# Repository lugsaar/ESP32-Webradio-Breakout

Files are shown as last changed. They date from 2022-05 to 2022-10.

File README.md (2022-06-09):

# ESP32-Webradio-Breakout

This project is a basic board to build an ESP32 webradio. All components like the microcontroller, 
display and the power supply should be compactly placed on a kind of breakout board. As an idea we used a
[blog article](https://www.az-delivery.de/blogs/azdelivery-blog-fur-arduino-und-raspberry-pi/internet-radio-mit-dem-esp32) 
of the company AZ-Delivery in March 2022. You only need a small handful of electronic components execpt 
an ESP32 development board and a I2C display.

By choosing a switching regulator for the power supply, leftover power supplies e.g. of an old scanner, 
PC speakers or similar can be used to run the board. From defective devices one has these power supplies
often lie around and can recycle them so here.

## technical details

coming later

## current state

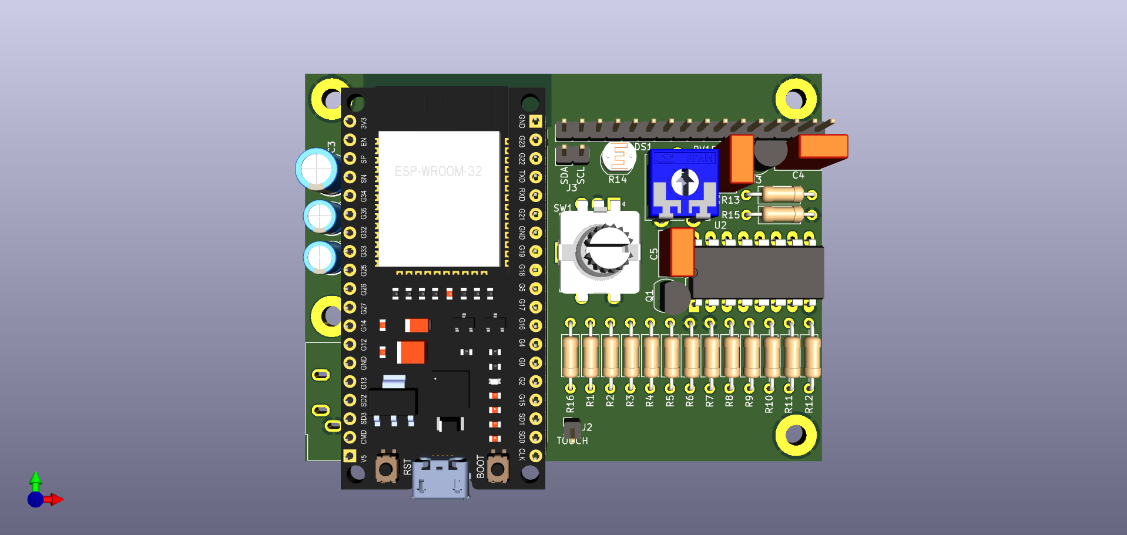
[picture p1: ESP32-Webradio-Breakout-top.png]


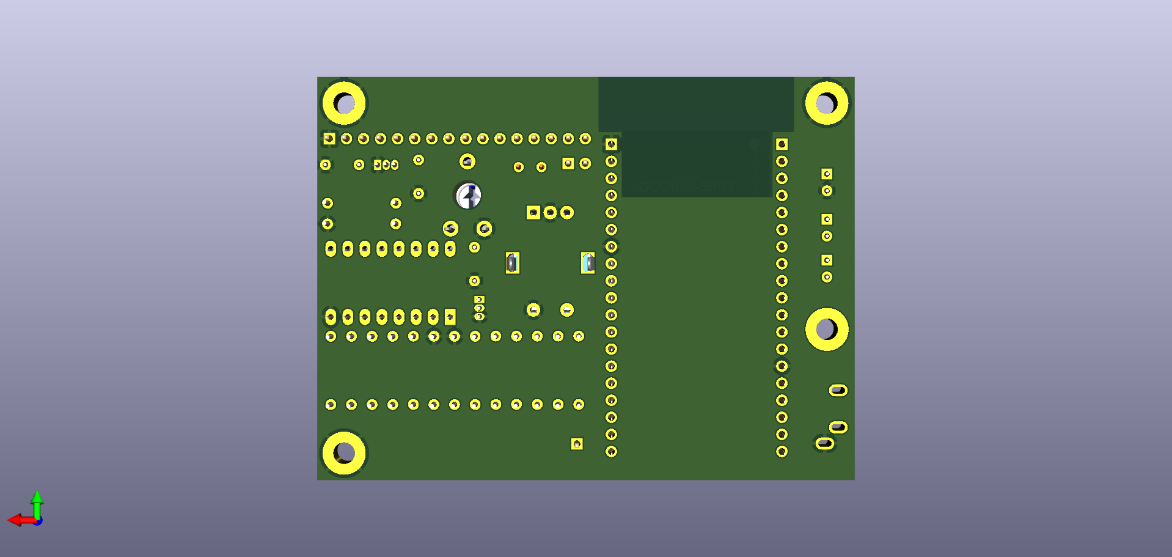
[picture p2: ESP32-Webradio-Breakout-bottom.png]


## maintained

- [Dominik](mailto:dominik@lug-saar.de) (LUG-Saar)
- [Manfred](mailto:mancas@lug-saar.de) (LUG-Saar)
- [Thomas](mailto:mase@setho.org) (TKS)

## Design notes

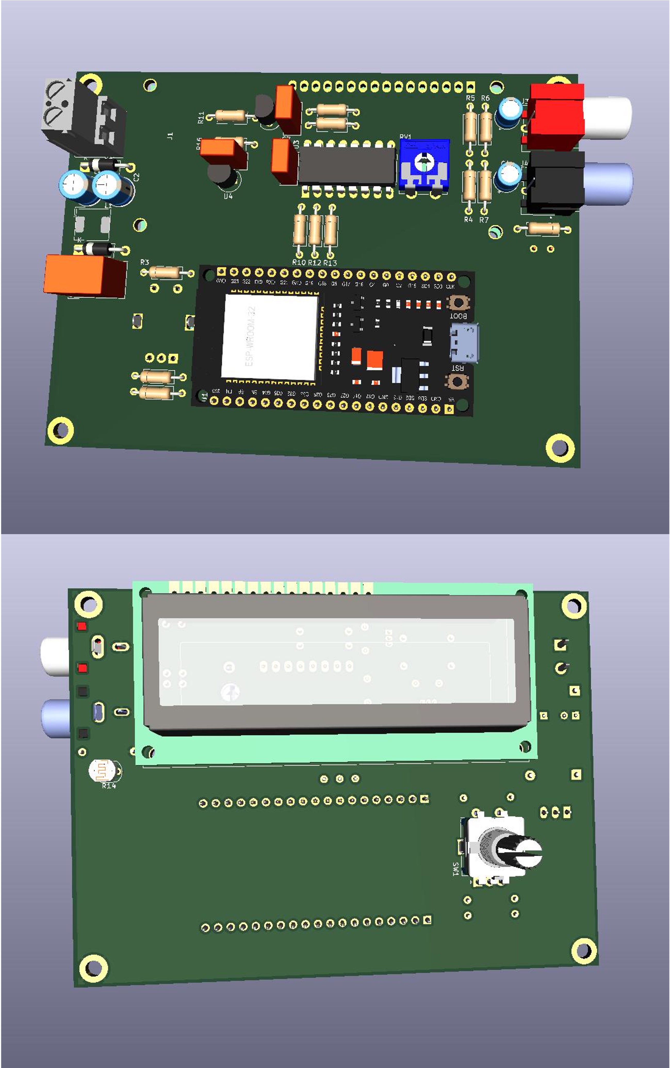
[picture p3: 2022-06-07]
ESP32-Webradio-Breakout.jpg

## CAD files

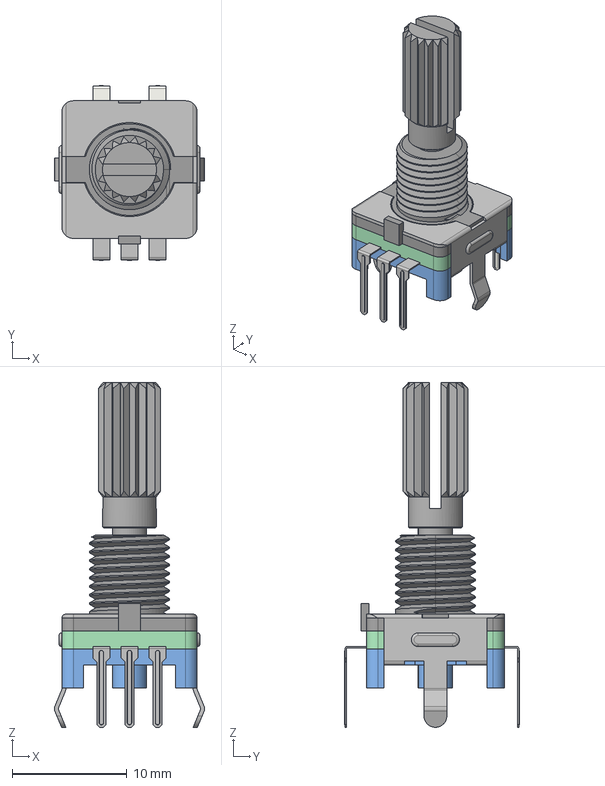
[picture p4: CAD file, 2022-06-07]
3D Models/EC11_Rotary_Encoder_Switched.step
13.1 x 15.3 x 30.1 mm

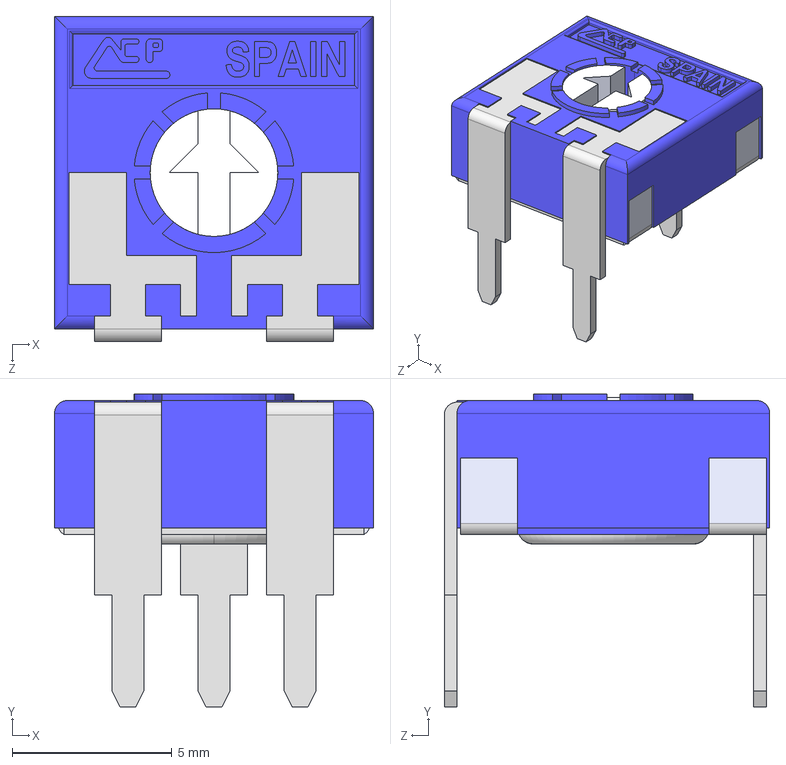
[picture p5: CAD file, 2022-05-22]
3D Models/Potentiometer_ACP_CA9-V10_Vertical_Hole.step
10.0 x 9.80 x 10.2 mm

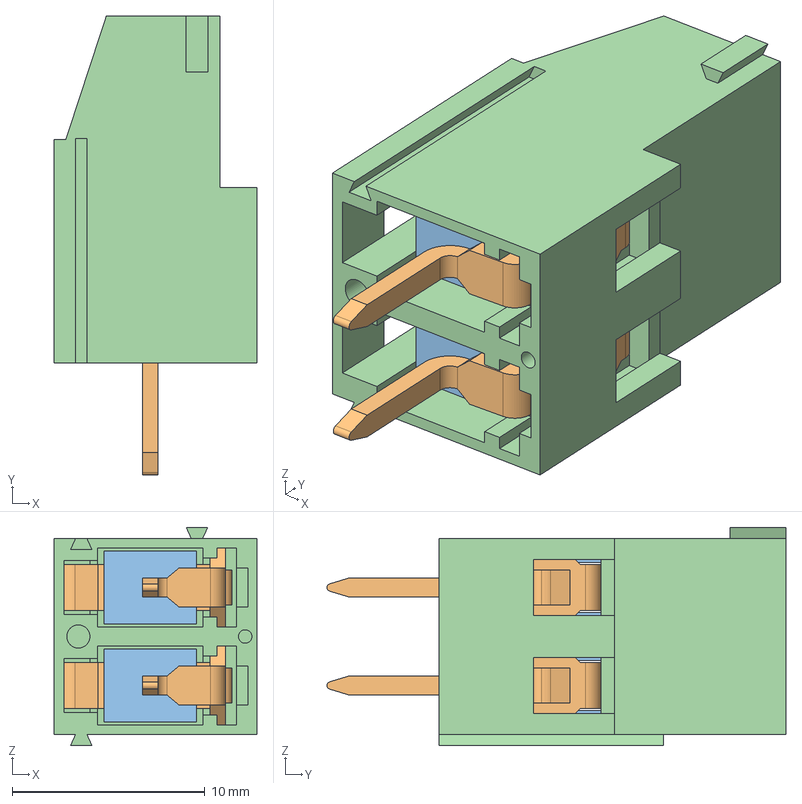
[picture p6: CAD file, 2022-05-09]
3D Models/TerminalBlock_RND_205-00287_1x02_P5.08mm_Horizontal.stp
10.5 x 23.8 x 11.3 mm

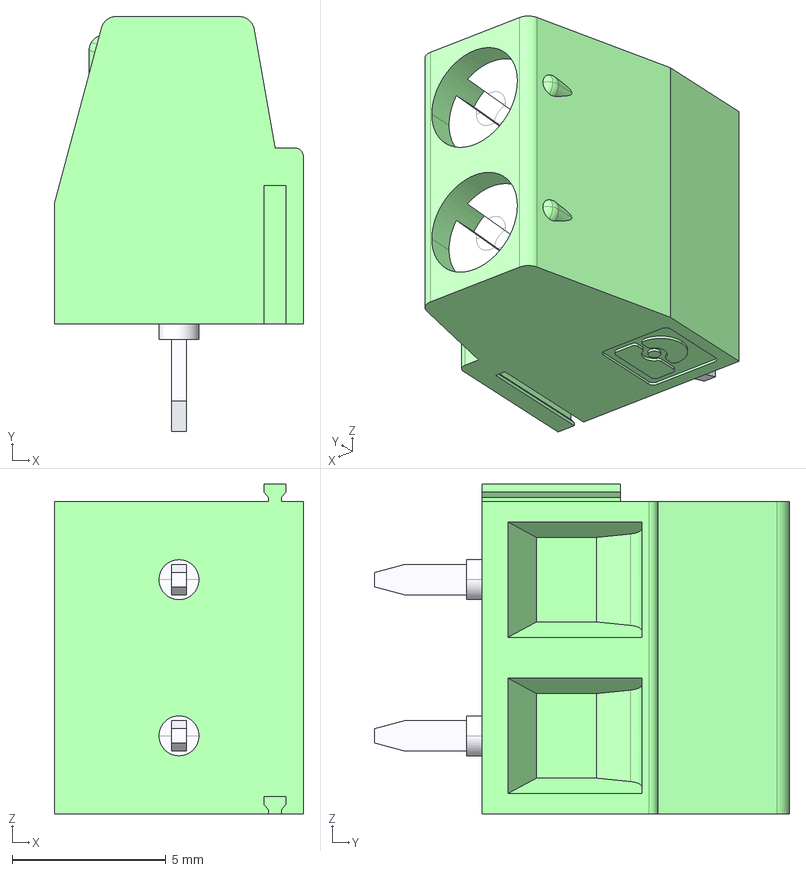
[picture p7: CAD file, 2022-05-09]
3D Models/TerminalBlock_Phoenix_MKDSN-1,5-2-5.08_1x02_P5.08mm_Horizontal.stp
8.10 x 13.5 x 10.7 mm

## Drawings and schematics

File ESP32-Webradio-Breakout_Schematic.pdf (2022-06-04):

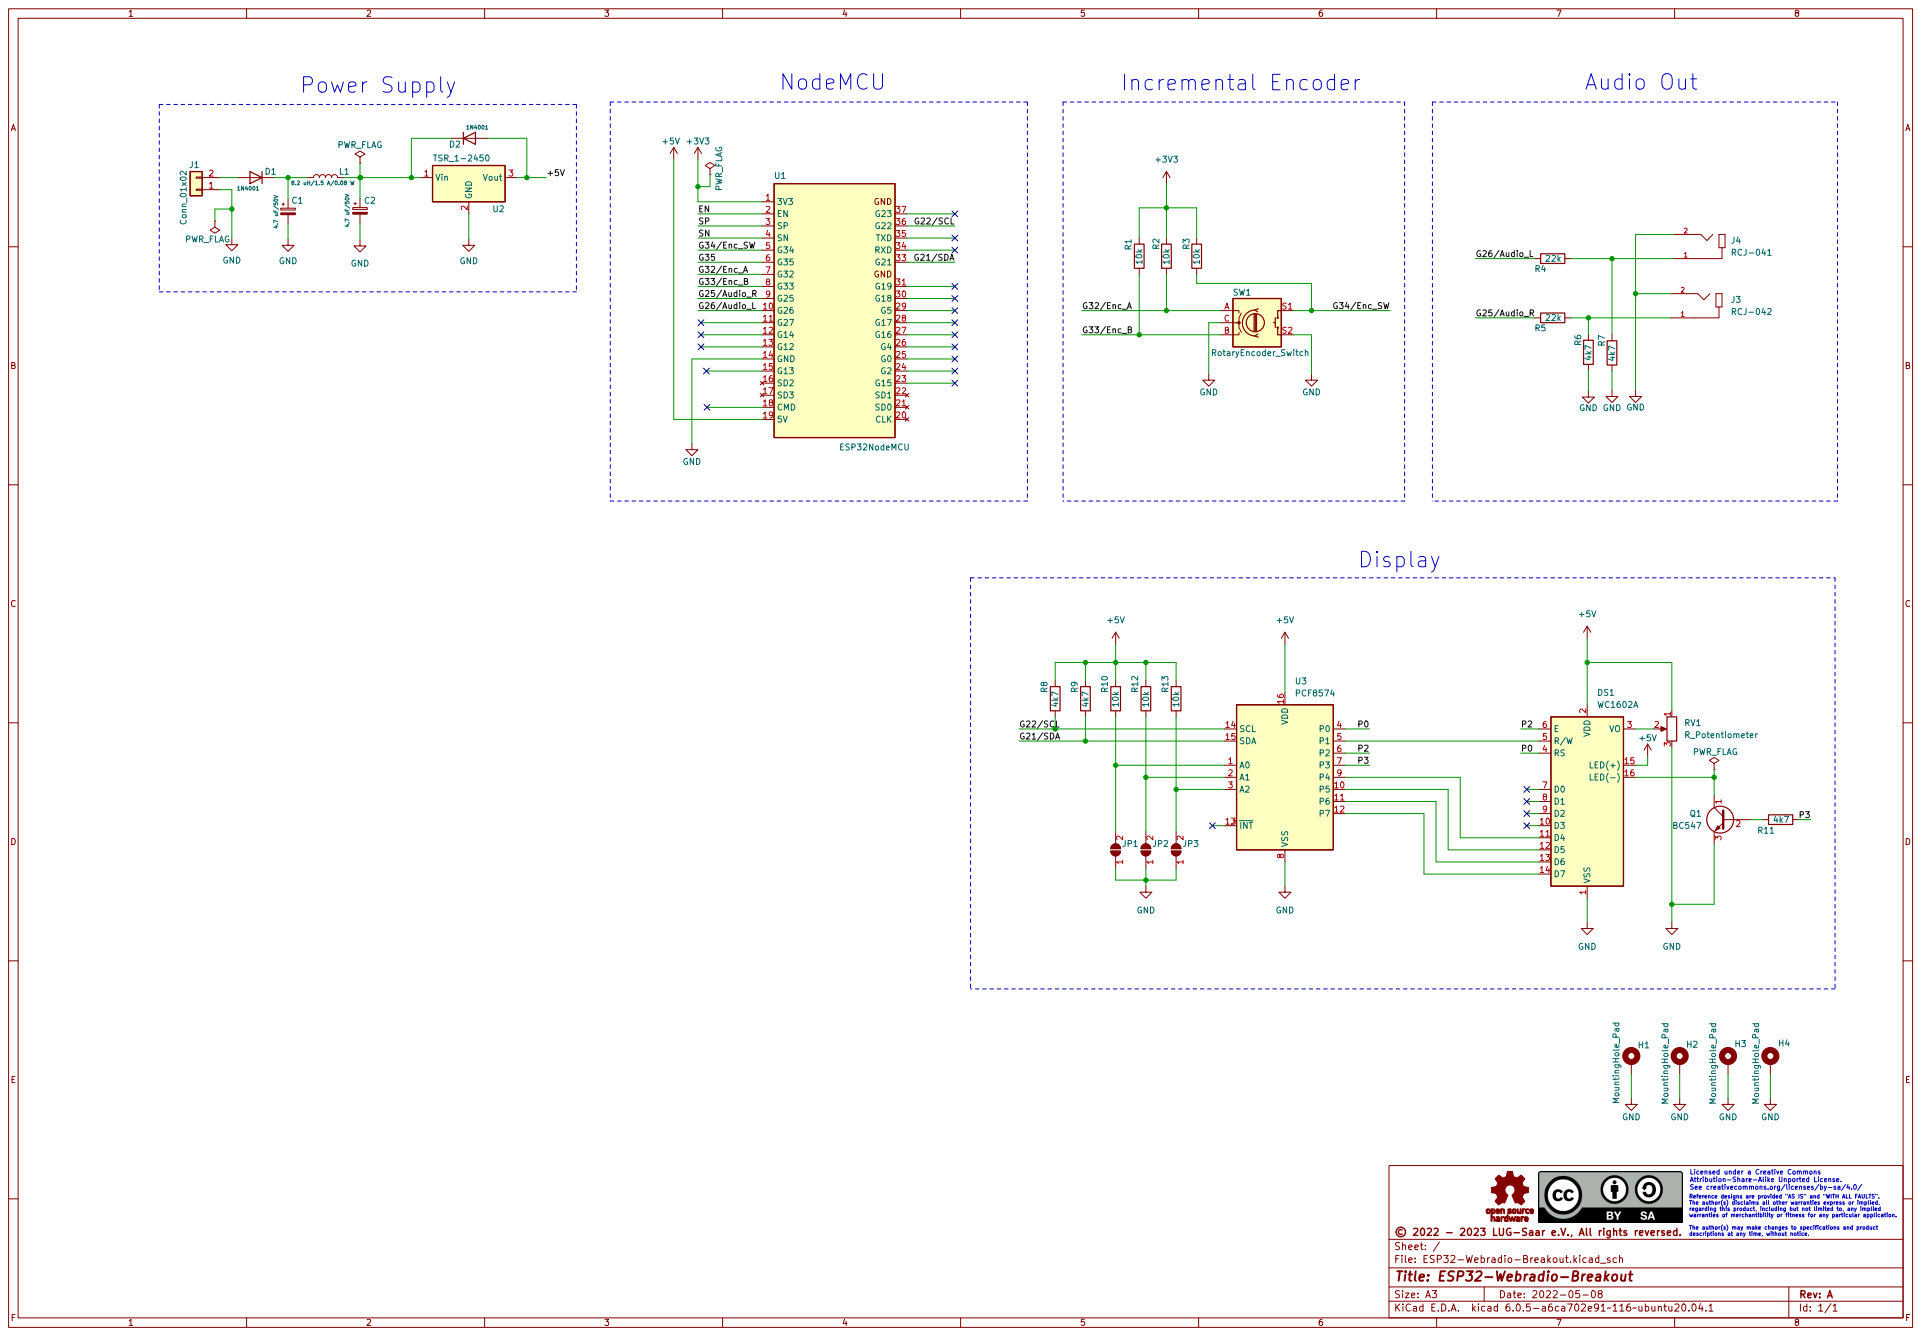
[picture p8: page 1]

Reference designs are provided "AS IS" and "WITH ALL FAULTS". The author(s) disclaims all other warranties express or implied, regarding this product, including but not limited to, any implied warranties of merchantibility or fitness for any particular application. The author(s) may make changes to specifications and product descriptions at any time, without notice. Licensed under a Creative Commons Attribution-Share-Alike Unported License. See creativecommons.org/licenses/by-sa/4.0/

File: ESP32-Webradio-Breakout.kicad_sch Sheet: / þÿ© 2022 - 2023 LUG-Saar e.V., All rights reversed.

Id: 1/1 Title: ESP32-Webradio-Breakout

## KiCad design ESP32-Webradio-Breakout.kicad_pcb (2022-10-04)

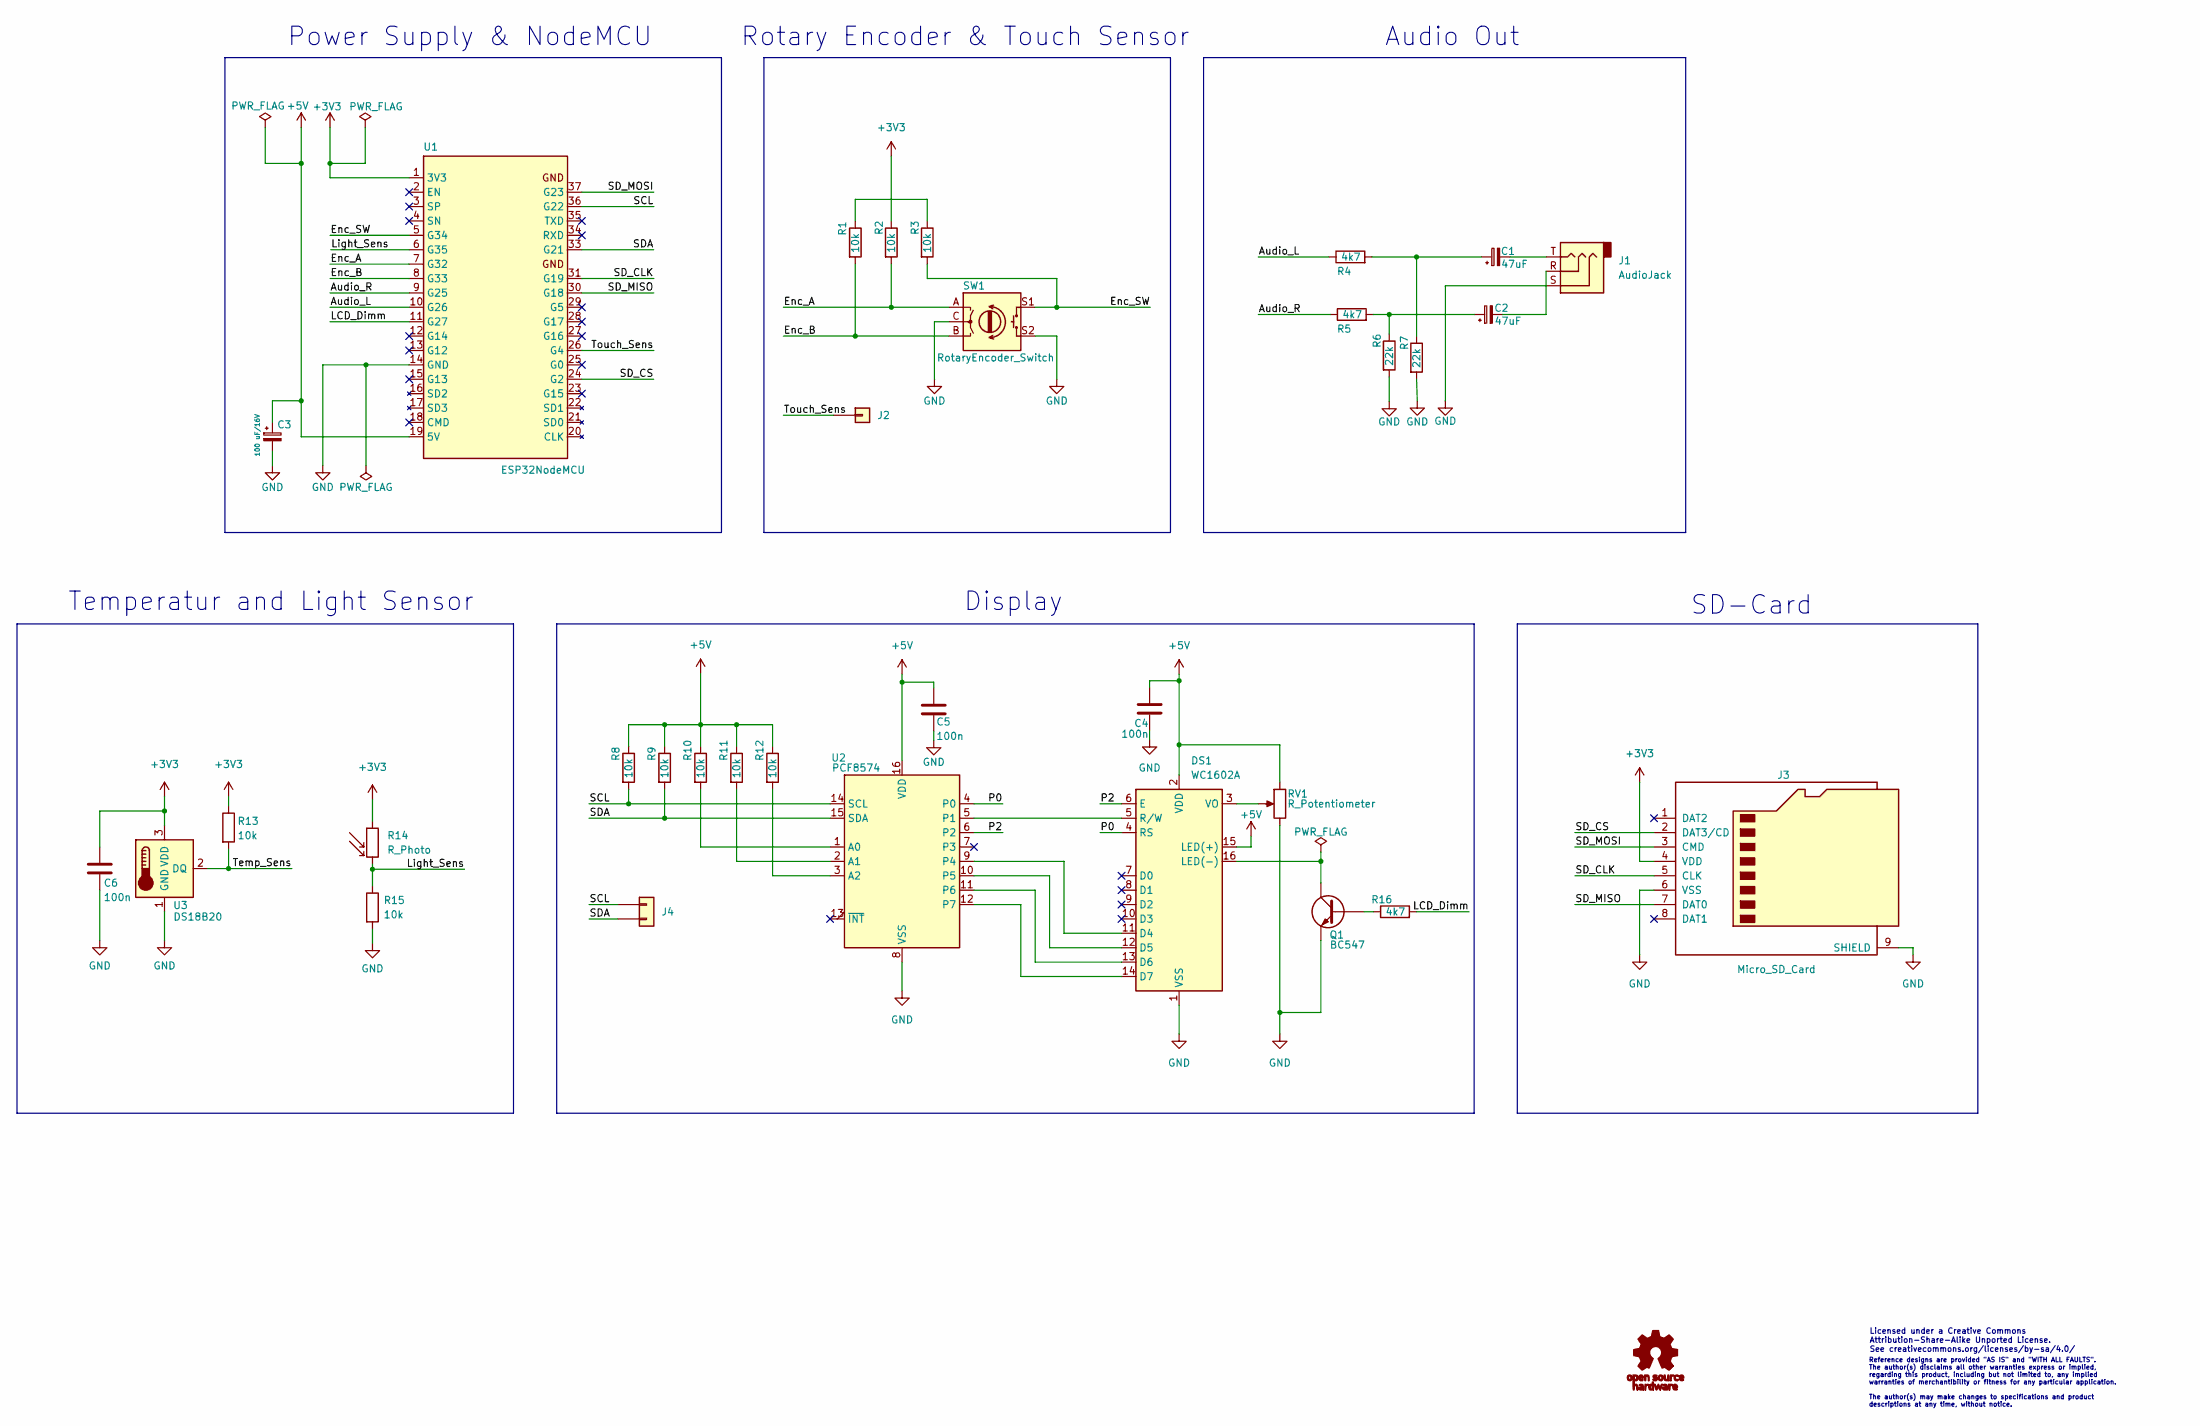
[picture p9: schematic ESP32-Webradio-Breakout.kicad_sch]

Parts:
C1, C2: 47uF; CP_Radial_D5.0mm_P2.50mm
C3: 100 uF/16V; CP_Radial_D6.3mm_P2.50mm
C4, C5, C6: 100n; C_Rect_L7.0mm_W3.5mm_P5.00mm
DS1: WC1602A; PinHeader_1x16_P2.54mm_Vertical
J1: AudioJack; Jack_3.5mm_CUI_SJ1-3533NG_Horizontal
J2: Conn_01x01; PinHeader_1x01_P2.54mm_Vertical
J3: Micro_SD_Card; PinHeader_1x08_P2.54mm_Vertical
J4: Conn_01x02; PinHeader_1x02_P2.54mm_Vertical
Q1: BC547; TO-92_Inline
R1, R2, R3, R8, R9, R10, R11, R12, R13, R15: 10k; R_Axial_DIN0207_L6.3mm_D2.5mm_P10.16mm_Horizontal
R4, R5, R16: 4k7; R_Axial_DIN0207_L6.3mm_D2.5mm_P10.16mm_Horizontal
R6, R7: 22k; R_Axial_DIN0207_L6.3mm_D2.5mm_P10.16mm_Horizontal
R14: R_Photo; R_LDR_5.1x4.3mm_P3.4mm_Vertical
RV1: R_Potentiometer; Potentiometer_ACP_CA9-V10_Vertical_Hole
SW1: RotaryEncoder_Switch; RotaryEncoder_Alps_EC11E-Switch_Vertical_H20mm
U1: ESP32NodeMCU; ESP32-NodeMCU_WROOM_32
U2: PCF8574; DIP-16_W10.16mm_LongPads
U3: DS18B20; TO-92_Inline

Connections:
+3V3: C6.1, J3.4 (VDD), R2.1, R13.1, R14.1, U1.1 (3V3), U3.3 (VDD)
+5V: C3.1, C4.1, C5.1, DS1.2 (VDD), DS1.15 (LED(+)), R8.1, R9.1, R10.1, R11.1, R12.1, RV1.1, U1.19 (5V), U2.16 (VDD)
/Audio_L: R4.1, U1.10 (G26)
/Audio_R: R5.1, U1.9 (G25)
/Enc_A: R2.2, SW1.A, U1.7 (G32)
/Enc_B: R1.2, SW1.B, U1.8 (G33)
/Enc_SW: R3.2, SW1.S1, U1.5 (G34)
/LCD_Dimm: R16.2, U1.11 (G27)
/Light_Sens: R14.2, R15.1, U1.6 (G35)
/P0: DS1.4 (RS), U2.4 (P0)
/P2: DS1.6 (E), U2.6 (P2)
/SCL: J4.1, R8.2, U1.36 (G22), U2.14 (SCL)
/SDA: J4.2, R9.2, U1.33 (G21), U2.15 (SDA)
/SD_CLK: J3.5 (CLK), U1.31 (G19)
/SD_CS: J3.2 (DAT3/CD), U1.24 (G2)
/SD_MISO: J3.7 (DAT0), U1.30 (G18)
/SD_MOSI: J3.3 (CMD), U1.37 (G23)
/Temp_Sens: R13.2, U3.2 (DQ)
/Touch_Sens: J2.1, U1.26 (G4)
GND: C3.2, C4.2, C5.2, C6.2, DS1.1 (VSS), J1.S, J3.6 (VSS), J3.9 (SHIELD), Q1.3 (E), R6.2, R7.2, R15.2, RV1.3, SW1.C, SW1.S2, U1.14 (GND), U1.32 (GND), U1.38 (GND), U2.8 (VSS), U3.1 (GND)
unnamed: C1.1, R4.2, R7.1
unnamed: C1.2, J1.T
unnamed: C2.1, R5.2, R6.1
unnamed: C2.2, J1.R
unnamed: DS1.3 (VO), RV1.2
unnamed: DS1.5 (R/W), U2.5 (P1)
unnamed: DS1.11 (D4), U2.9 (P4)
unnamed: DS1.12 (D5), U2.10 (P5)
unnamed: DS1.13 (D6), U2.11 (P6)
unnamed: DS1.14 (D7), U2.12 (P7)
unnamed: DS1.16 (LED(-)), Q1.1 (C)
unnamed: Q1.2 (B), R16.1
unnamed: R1.1, R3.1
unnamed: R10.2, U2.1 (A0)
unnamed: R11.2, U2.2 (A1)
unnamed: R12.2, U2.3 (A2)

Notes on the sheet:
Display
Licensed under a Creative Commons Attribution-Share-Alike Unported License. See creativecommons.org/licenses/by-sa/4.0/
Reference designs are provided "AS IS" and "WITH ALL FAULTS". The author(s) disclaims all other warranties express or implied, regarding this product, including but not limited to, any implied warranties of merchantibility or fitness for any particular application. The author(s) may make changes to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
Temperatur and Light Sensor
SD-Card
Power Supply & NodeMCU
Rotary Encoder & Touch Sensor
Audio Out

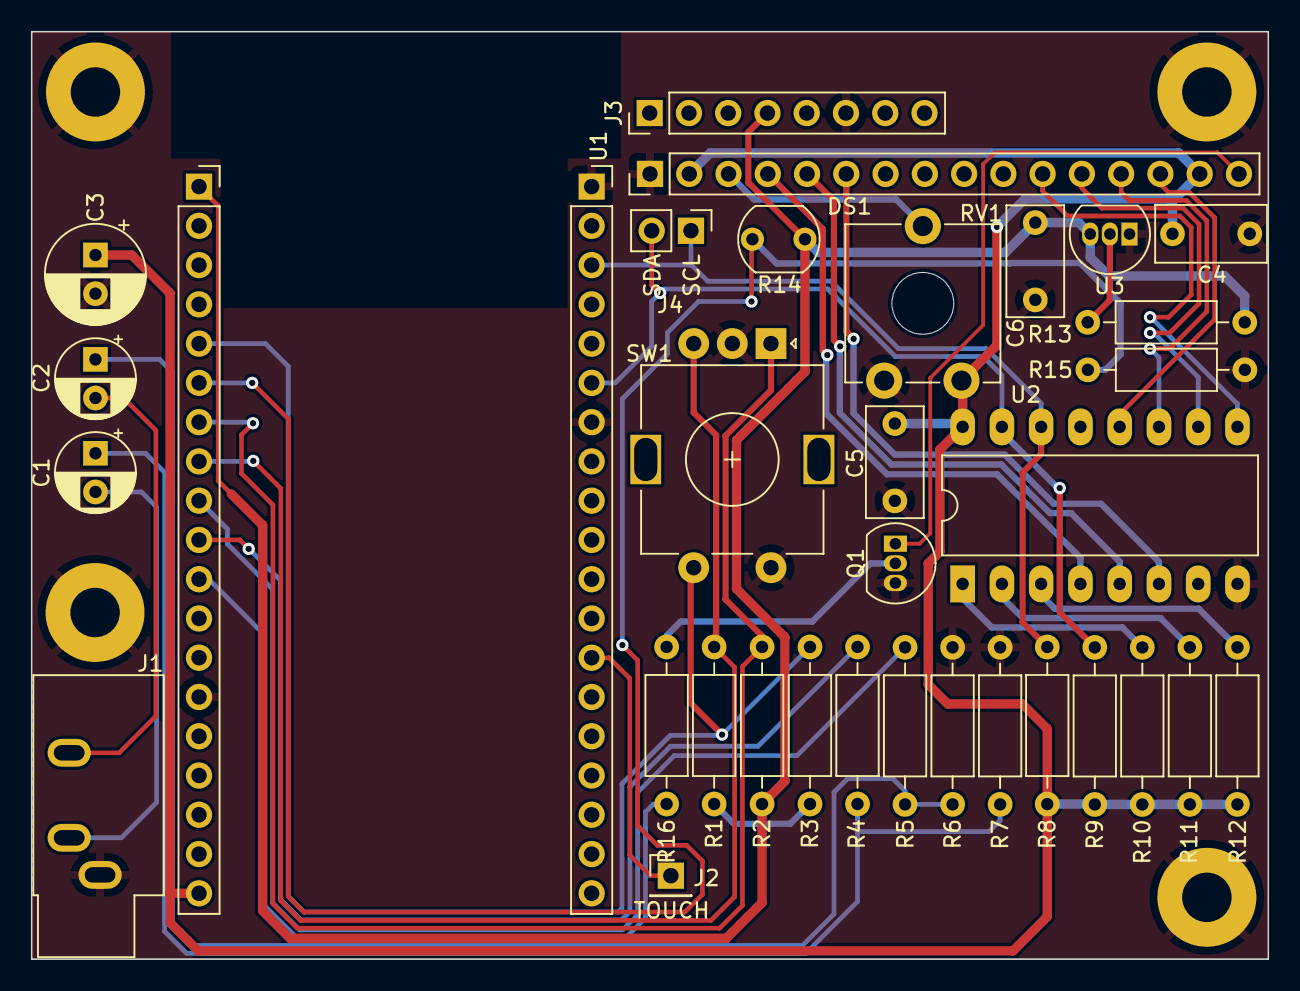
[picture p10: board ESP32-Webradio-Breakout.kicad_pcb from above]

Board: 2 copper layers, 80.0 x 60.0 mm, 33 parts (0 on the bottom side), 36 nets.

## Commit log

2022-04-30 first init
    [ESP32-Webradio-Breakout.kicad_pcb, ESP32-Webradio-Breakout.kicad_sch]
2022-04-30 adding RCA Jack Connector to board
    [ESP32-Webradio-Breakout.kicad_pcb, ESP32-Webradio-Breakout.kicad_sch]
2022-05-07 adding ESP32-NodeMCU to Project Lib
    [ESP32-Webradio-Breakout.kicad_pcb, ESP32-Webradio-Breakout.kicad_sch]
2022-05-09 adding CC BY-SA 4.0 licens to the Project
    [ESP32-Webradio-Breakout.kicad_pcb, ESP32-Webradio-Breakout.kicad_sch, TerminalBlock_Phoenix_MKDSN-1,5-2-5.08_1x02_P5.08mm_Horizontal.stp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]
2022-05-17 adding some Power Supply components
    [ESP32-Webradio-Breakout.kicad_pcb, ESP32-Webradio-Breakout.kicad_sch]
2022-05-21 Display and Remote 8-Bit I/O Expander for I2C added
    [ESP32-Webradio-Breakout.kicad_pcb, ESP32-Webradio-Breakout.kicad_sch]
2022-05-22 Adding 3D Model for Potentiometer ACP-CA9-V10
    [ESP32-Webradio-Breakout.kicad_pcb, ESP32-Webradio-Breakout.kicad_sch, Potentiometer_ACP_CA9-V10_Vertical_Hole.step]
2022-05-23 Adding NPN-Transistor to switch the Backlight
    [ESP32-Webradio-Breakout.kicad_pcb, ESP32-Webradio-Breakout.kicad_sch]
2022-06-04 adding some mounting holes and README file
    [ESP32-Webradio-Breakout.kicad_pcb, ESP32-Webradio-Breakout.kicad_sch]
2022-06-06 Adding Temperatur and Light Sensor. ICs need 100n Cap and DS18B20 connecting to MCU
    [ESP32-Webradio-Breakout.kicad_pcb, ESP32-Webradio-Breakout.kicad_sch]
2022-06-06 Cleanup schematic before adding a new branch.
    [ESP32-Webradio-Breakout.kicad_pcb, ESP32-Webradio-Breakout.kicad_sch]
2022-06-07 Changed PCF8574A to PCF8574
    [ESP32-Webradio-Breakout.kicad_sch]
2022-06-07 Added solder pads for I2C display
    [ESP32-Webradio-Breakout.kicad_pcb, ESP32-Webradio-Breakout.kicad_sch]
2022-06-07 adding 3D Model for Rotary Encoder
    [EC11_Rotary_Encoder_Switched.step, ESP32-Webradio-Breakout.kicad_pcb]
2022-06-09 Added electrolytic capacitor to 5V line
    [ESP32-Webradio-Breakout.kicad_pcb, ESP32-Webradio-Breakout.kicad_sch]
2022-06-09 Parts placement Updated README Updated Images
    [ESP32-Webradio-Breakout.kicad_pcb, ESP32-Webradio-Breakout.kicad_sch]
2022-06-09 Removed 24V supply
    [ESP32-Webradio-Breakout.kicad_pcb, ESP32-Webradio-Breakout.kicad_sch]
2022-06-09 Replaced Cinch Jacks by 3.5mm Jack New parts placement
    [ESP32-Webradio-Breakout.kicad_pcb, ESP32-Webradio-Breakout.kicad_sch]
2022-06-09 Increased keepout area for wifi
    [ESP32-Webradio-Breakout.kicad_pcb]
2022-06-10 Regrouped NodeMCU
    [ESP32-Webradio-Breakout.kicad_pcb]
2022-06-11 Rotated display connector 180 degrees
    [ESP32-Webradio-Breakout.kicad_pcb]
2022-06-11 Flipped left and right for a better display connection
    [ESP32-Webradio-Breakout.kicad_pcb]
2022-06-12 Added pin for touch sensor Some regrouping
    [ESP32-Webradio-Breakout.kicad_pcb, ESP32-Webradio-Breakout.kicad_sch]
2022-06-15 Rotated display connector by 180 degrees
    [ESP32-Webradio-Breakout.kicad_pcb]
2022-06-18 routing first tracks
    [ESP32-Webradio-Breakout.kicad_pcb]
2022-07-01 Added MicroSD cardreader
    [ESP32-Webradio-Breakout.kicad_pcb, ESP32-Webradio-Breakout.kicad_sch]
2022-07-09 everything routed the first time, some ground connections still need to be done properly.
    [ESP32-Webradio-Breakout.kicad_pcb]
2022-08-07 changing value of R6 and R7 to 22k. moving some tracks nicely
    [ESP32-Webradio-Breakout.kicad_pcb, ESP32-Webradio-Breakout.kicad_sch]
2022-10-04 connecting the microSD slot with MCU in the schematic via SPI
    [ESP32-Webradio-Breakout.kicad_pcb, ESP32-Webradio-Breakout.kicad_sch]
